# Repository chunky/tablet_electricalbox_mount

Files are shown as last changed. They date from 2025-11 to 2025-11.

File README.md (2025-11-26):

# Tablet Wall Mount for Electrical Box

## Introduction

I wanted to be able to mount a tablet to a wall, with two main
requirements:

1. Easily removeable without leaving any wall repairs to be done, when
    I chose to remove it.
1. Convenient management for powering the tablet and avoiding visible
    wires.

This design works off the idea that you can have power in an electrical
box in the wall, then screw this holder to the standard fittings on the
electrical box. If/when you want rid of it, just take it off and replace
it with a blanking plate, or a cover plate that makes the electricity
otherwise available.

There's a slot for a power cable, and the bottom is broad enough to hide
the connector where it meets the tablet.

Since I already have PoE in my house, I ran PoE to the electrical box
then had a PoE-to-tablet-connector converter.

## This is what it looks like

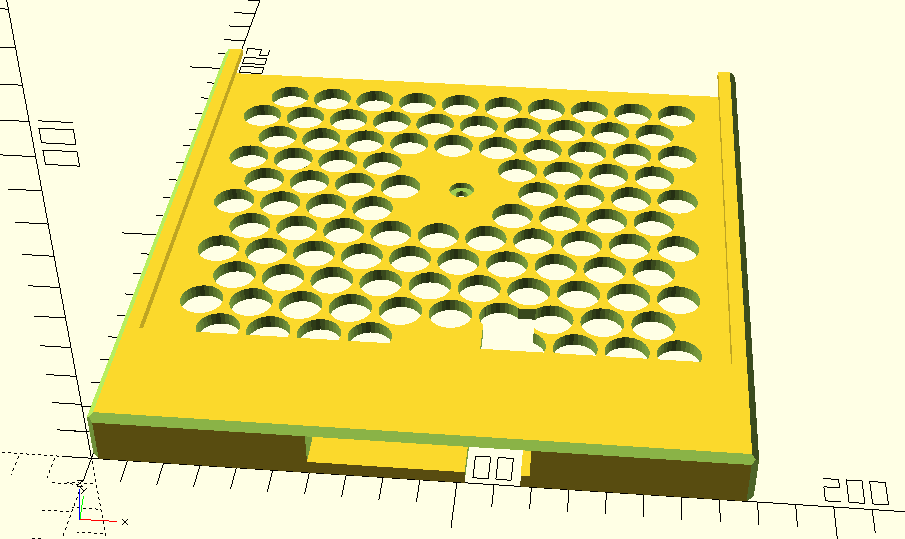
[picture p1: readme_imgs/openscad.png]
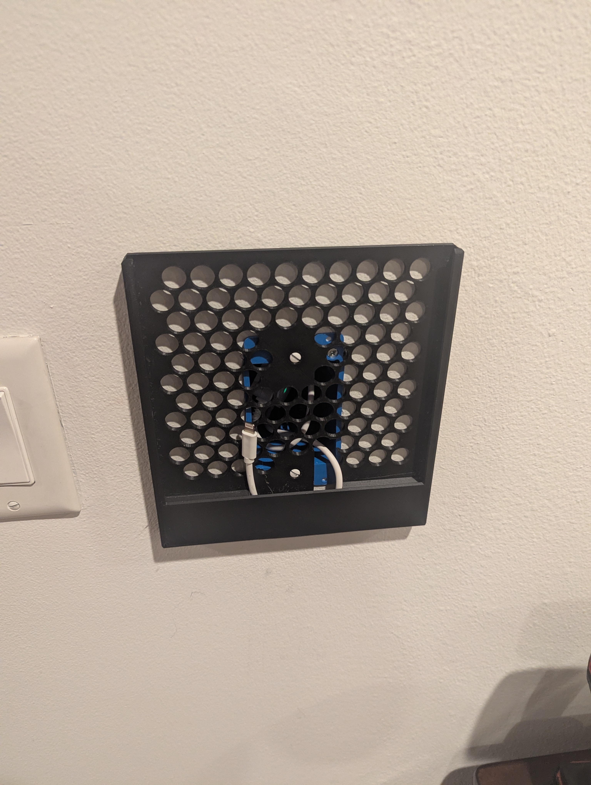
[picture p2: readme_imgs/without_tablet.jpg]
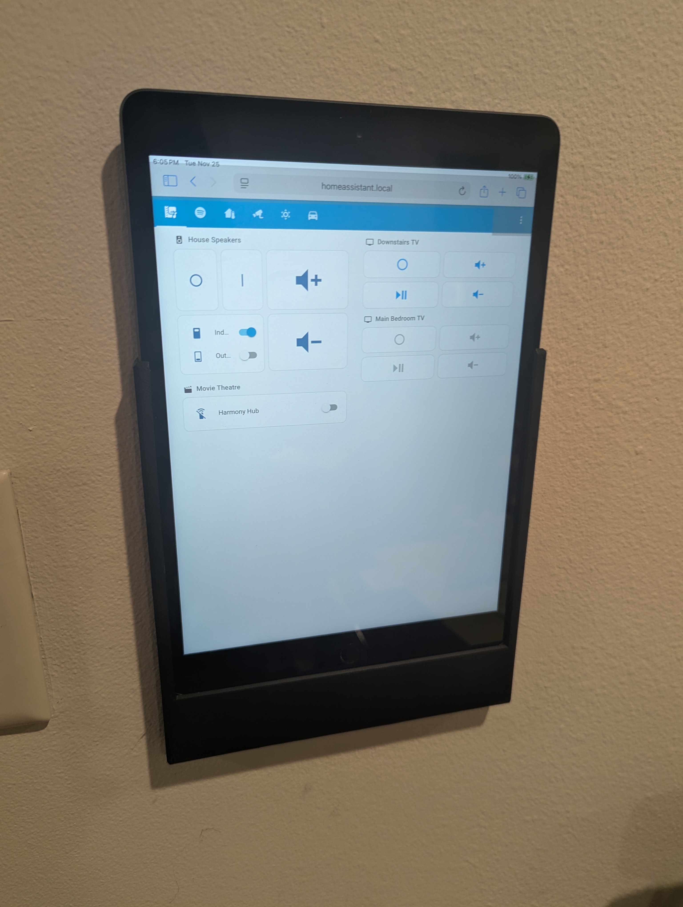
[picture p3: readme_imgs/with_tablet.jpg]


## Making it work for you

The SCAD file has lots of parameters at the top. The most important are
```tablet_width```, ```tablet_height```, and ```tablet_depth```
to fit whatever tablet you have.

Gary <chunkyks@gmail.com>

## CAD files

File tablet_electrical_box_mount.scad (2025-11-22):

// Tablet Kiosk Wall Mount for Single-Gang Electrical Box

// Designed to mount to standard single-gang box screws
// Open top for sliding tablet in, cable management at bottom

// Clearance to add to tablet dimensions
tablet_clearance = 1.0;
// iPad dimensions (iPad 8th Gen model A2270 - 10.2 inch)
tablet_width = 174.1 + tablet_clearance;  // 6.8 inches
tablet_height = 250.6 + tablet_clearance; // 9.8 inches
tablet_depth = 7.5 + tablet_clearance;    // 0.29 inches

// Frame parameters
frame_width = 2;  // Width of frame border
frame_depth = 11.5; // How deep the frame pocket is
wall_plate_thickness = 4; // Back plate against wall
lip_height = 4;   // Small lip to hold iPad sides and bottom
bottom_frame_height = 35;  // Taller bottom frame to cover USB plug
cable_channel_width = 15;  // Narrow channel at front for cable only
cable_clearance_back = 60;  // Wide clearance in back for connector

// Single-gang box parameters
gang_box_screw_spacing = 83.3;  // Standard vertical spacing
gang_box_width = 70;

// Cable clearance hole in back plate - positioned between the screw holes but offset to the side
// This is where cable exits from center of electrical box
cable_offset = 20;  // Offset to side of screws
cable_clearance_width = 30; // Width of slot cable goes through
cable_clearance_height = 50; // Cabling gap

// Skeletonize back plate. Simplify, then add lightness
hole_spacing = 15;
hole_dia = 13;

// Bevel parameters
bevel_size = 2;  // Size of front edge bevels

// Testing option - set to true to print only bottom half for test fitting
test_bottom_only = false;  // Change to true for test print

// Bambu A1 printer constraint - max Y build dimension is 256mm
max_build_y = 195;
// Calculate the actual frame height to use (limited by printer)
frame_y_height = min(tablet_height + bottom_frame_height, max_build_y - 2*frame_width);

// Module to create a 45-degree chamfer cut
module bevel(length, size=bevel_size) {
    rotate([0, 90, 0])
    linear_extrude(length)
        polygon([[0, 0], [size, 0], [0, size]]);
}

module main_body() {
    difference() {
        union() {
            // Main back plate with reinforcement ribs
            cube([tablet_width + 2*frame_width,
                  frame_y_height,  // Limited by printer build volume
                  wall_plate_thickness]);
            
            // Side frames (left and right)
            cube([frame_width, frame_y_height,
                  wall_plate_thickness + frame_depth]);

            translate([tablet_width + frame_width, 0, 0])
                cube([frame_width, frame_y_height,
                      wall_plate_thickness + frame_depth]);
            
            // Bottom frame with cable channel - taller to cover USB plug
            difference() {
                cube([tablet_width + 2*frame_width, bottom_frame_height,
                      wall_plate_thickness + frame_depth]);

                // Wide cable clearance in back for connector - does NOT go through to front
                translate([frame_width + tablet_width/2 - cable_clearance_back/2,
                           -1,
                           wall_plate_thickness])
                cube([cable_clearance_back,
                          3*bottom_frame_height + 2,
                          frame_depth - 2]);  // Stops before reaching front face

                // Opening at very bottom for USB cable to plug into iPad from below
                translate([frame_width + tablet_width/2 - cable_channel_width/2,
                           -1,
                           -1])
                    cube([cable_channel_width,
                          10*frame_width + 2,  // Just through the bottom edge
                          wall_plate_thickness + 2]);
            }
            
            // Small lips on sides to hold iPad
            translate([frame_width, frame_width, wall_plate_thickness + tablet_depth])
                cube([lip_height, frame_y_height - frame_width, frame_depth - tablet_depth]);

            translate([frame_width + tablet_width - lip_height, frame_width, wall_plate_thickness + tablet_depth])
                cube([lip_height, frame_y_height - frame_width, frame_depth - tablet_depth]);

            // Bottom lip extends fully across - NO gap at front
            translate([frame_width, frame_width, wall_plate_thickness + tablet_depth])
                cube([tablet_width, bottom_frame_height, frame_depth - tablet_depth]);
        }
        
        // Mounting screw holes (standard single-gang spacing)
        screw_hole_dia = 4;
        screw_from_bottom = frame_width + tablet_height/3 - gang_box_screw_spacing/2;  // Screws center 1/3 up tablet

        // Vertical cable channel from electrical box (between screws) down to iPad charging port
        translate([frame_width + tablet_width/2 + cable_offset - cable_channel_width/2,
                   -1,
                   -1])
            cube([cable_channel_width,
                  screw_from_bottom + cable_clearance_height/2 + 1,
                  wall_plate_thickness + tablet_depth - 1]);

        translate([frame_width + tablet_width/2, screw_from_bottom, -1])
            cylinder(h=wall_plate_thickness + 2, d=screw_hole_dia, $fn=30);

        translate([frame_width + tablet_width/2, screw_from_bottom + gang_box_screw_spacing, -1])
            cylinder(h=wall_plate_thickness + 2, d=screw_hole_dia, $fn=30);

        // Countersink for screw heads
        translate([frame_width + tablet_width/2, screw_from_bottom, wall_plate_thickness/2])
            cylinder(h=wall_plate_thickness, d=8, $fn=30);

        translate([frame_width + tablet_width/2, screw_from_bottom + gang_box_screw_spacing, wall_plate_thickness/2])
            cylinder(h=wall_plate_thickness, d=8, $fn=30);
        
        // Brick-pattern offset holes for better strength and material savings
        // Move circles closer in Y-direction to account for offsets
        y_adjustment = 1.2;
        for(y_index = [3 : floor(y_adjustment * (frame_y_height - hole_dia) / hole_spacing) - 1]) {
            y = hole_spacing + y_index * hole_spacing / y_adjustment;
            // Offset every other row by half spacing for brick pattern
            x_offset = (y_index % 2) * hole_spacing / 2;

            for(x = [-tablet_width/2 + hole_spacing : hole_spacing : tablet_width/2 - hole_spacing]) {
                // Skip holes near mounting screws
                if (abs((tablet_width/2 + x + x_offset) - tablet_width/2) > 15 ||
                    (abs(y - screw_from_bottom) > 15 &&
                     abs(y - (screw_from_bottom + gang_box_screw_spacing)) > 15)) {
                    translate([frame_width + tablet_width/2 + x + x_offset, y, -1])
                        cylinder(h=wall_plate_thickness + 2, d=hole_dia, $fn=30);
                }
            }
        }
    }
}

// Module to apply bevels to all front edges
module beveled_body() {
    front_z = wall_plate_thickness + frame_depth;
    total_width = tablet_width + 2*frame_width;

    difference() {
        
        main_body();

        // Left side frame - outer front edge (vertical along Y)
        translate([0, 0, front_z])
            rotate([270, 0, 90])
            bevel(frame_y_height);

        // Right side frame - outer front edge (vertical along Y)
        translate([total_width, 0, front_z])
            rotate([0, 0, 90])
            bevel(frame_y_height);

        // Bottom frame - outer front edge (horizontal along X)
        translate([0, 0, front_z])
            bevel(total_width);

        // Top frame - outer front edge (horizontal along X)
        translate([0, frame_y_height, front_z])
            rotate([270, 0, 0])
            bevel(total_width);
            
        // Bottom left frame corner
        rotate([180, 270, 180])
            bevel(frame_depth+wall_plate_thickness);
        
        // Bottom right frame corner
        translate([total_width, 0, 0])
        rotate([180, 270, 270])
            bevel(frame_depth+wall_plate_thickness);
            
        // Top left frame corner
        translate([0, frame_y_height, 0])
        rotate([180, 270, 90])
            bevel(frame_depth+wall_plate_thickness);

        // Top right frame corner
        translate([total_width, frame_y_height, 0])
        rotate([180, 270, 0])
            bevel(frame_depth+wall_plate_thickness);
    }
}

// Render the mount
if (test_bottom_only) {
    // Only render bottom half for testing - includes screws and cable management
    intersection() {
        beveled_body();
        translate([-10, -10, -1])
            cube([tablet_width + 2*frame_width + 20,
                  tablet_height/3,  // Half height plus extra for cable area
                  wall_plate_thickness + frame_depth + 2]);
    }
} else {
    // Render full mount
    beveled_body();
}

// Visual reference (comment out for printing)
%translate([frame_width, frame_width, wall_plate_thickness])
    cube([tablet_width, tablet_height, tablet_depth]);

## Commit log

2025-11-20 Limit printed object height to bed of 3d printer
    [ipad_electrical_box_mount.scad]
2025-11-20 Offset holes
    [ipad_electrical_box_mount.scad]
2025-11-20 Push skeletonising holes closer in Y-axis
    [ipad_electrical_box_mount.scad]
2025-11-20 Move holes away from edges, give tablet slightly more space
    [ipad_electrical_box_mount.scad]
2025-11-21 Move entire build to corner at 0,0,0 Make lip thicker Shrink entire build along Y axis
    [ipad_electrical_box_mount.scad]
2025-11-21 Bevel front outer edges
    [ipad_electrical_box_mount.scad]
2025-11-21 Fiddling numbers to experiment
    [ipad_electrical_box_mount.scad]
2025-11-21 Change "ipad" to tablet, comment all parameters in file
    [ipad_electrical_box_mount.scad]
2025-11-22 Expand spaces cables need
    [tablet_electrical_box_mount.scad]
2025-11-22 Improved cable management
